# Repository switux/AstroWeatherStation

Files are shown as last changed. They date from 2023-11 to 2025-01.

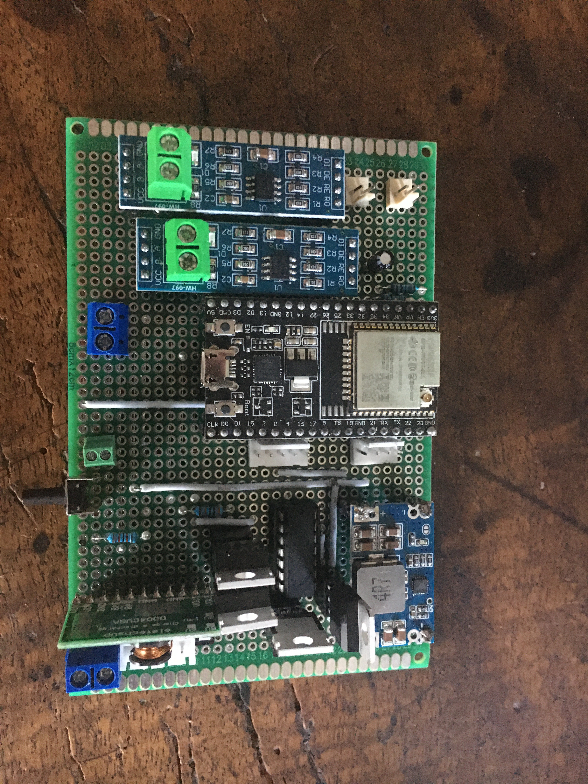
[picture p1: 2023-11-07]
schematics/perfboard_with_components.jpg

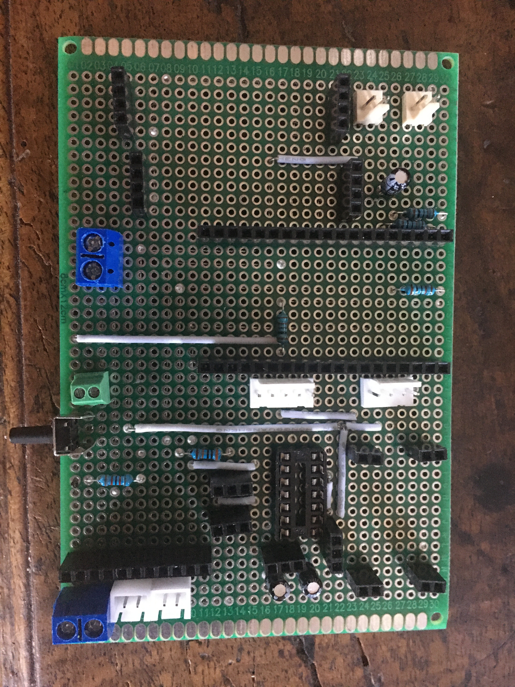
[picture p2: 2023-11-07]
schematics/perfboard_top_view.jpg

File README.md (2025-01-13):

# AstroWeatherStation

ESP32 based weather station with features to help operate an astronomical observatory.



## GOAL

This project aims to provide all the instructions that are needed to build a weather station for remote astronomical observatories.
On top of the usual environmental readings, rain events, cloud coverage and sky quality are reported to allow the safe operation of the observatory.

## PRE-REQUISITES (WIP)

## BUILD INSTRUCTIONS

  - Arduino IDE ( add the lines in bold to ~/.arduino15/packages/esp**xxxx**/hardware/esp**xxxx**/**{version}**/platform.local.txt )

    - The ALPACA web server uses regular expressions that need to be enabled, 

    **compiler.cpp.extra_flags=-DASYNCWEBSERVER_REGEX=1**

    - A sequential build number is embedded in the code every time a build is made (whether it is successful or not)

    **recipe.hooks.prebuild.0.pattern={build.source.path}/../build_seq.sh {build.source.path}**

    For the hook to work, you will also need to create a link (or copy the file) to the file "build.sh" from sketch directory to the path of the sketch book. Sorry for the mess ... if you have a better solution, you are most welcome!

## STATUS & DEVELOPMENT

This is version 3.0 of the project. The current version is 3.0.0 and has hit production.

New features in this version:

  - Hardware
    - Addition of POE module
    - Addition of optional GPS support
    - Addition of an optional I2C UART/GPIO extender (SC16IS750)
    - Two relays to control the observatory dome
    - Input to receive dome status
      
  - Software
    - ASCOM ALPACA Server
    - Support of ultrasonic wind sensors for adverse conditions (frost)
    - Dome closure upon rain event

Improvements:

  - Configuration UI
  - Removed configuration button and replaced by guard time on the reboot button (10s)
  - Clear/cloudy/overcast sky states instead of overcast/clear

The things that might be improved in v3.1 are:

  - Software
    - TBD
  - Hardware
    - TBD

## FEATURES

  - Weather parameters:
  
    - Temperature
    - Pressure
    - Relative humidity
    - Wind speed
    - Wind direction
    - Rain detection
    - Rain intensity
  
  - Astronomical parameters:
  
    - Cloud coverage
    - Solar irradiance
    - Sky Quality Meter
  
  - Alarms for:
  
    - Sensor unavailability
    - Rain event
    - Low battery
    - Rain sensor HW problem
  
  - Operations:

    - External reboot button
    - Debug button (to be pushed when rebooting to activate debug mode)
    - External micro USB socket for debugging (serial console) and firmware updates
    - Configuration mode and runtime configuration updates activable via button

## SPECIFICATIONS

This section is being reworked as there are different hardware setups.

  - Power consumption:
    - Solar panel version:
       - 12mA in sleep mode
       - ~40mA while active (for ~30s)
  - Autonomy: N/A (collecting data)
  - Measures (from sensor specs)
    - Illuminance range: 0-88k Lux ( up to ~730 W/m² )
    - Temperature range: -40°C to +85°C
    - Pressure: 300 to 1100 hPa
    - Wind speed: 0 to 60 m/s

## About the SQM feature

This is now validated.

    - 20°FoV lens put in front of the TSL2591 (comparable to the SQM-Lx)
    - Calibration against my SQM-LE done
    
## Open points

   - The RG9 sensor raises false positives during day because (I guess) of condensation. I try to mitigate this but since it is happening during daytime, it is only a minor issue.

## Runtime configuration interface

## Alarms format

The station sends alarm to an HTTPS endpoint as a JSON string:

{
  "subject": "reason for the alarm",
  "message": "what happened"
}

## Data format

The station sends the data to a web server as a JSON string:

{
  "battery_level":92,
  "timestamp":1675767261,
  "rain_event":0,
  "temp":16.84000015,
  "pres":941.1413574,
  "rh":27.296875,
  "lux":68181,
  "ambient":21.42998695,
  "sky":-3.19000864,
  "direction":45,
  "speed":0,
  "rain":0,
  "sensors":63
}

Where

- battery_level: in % of 4.2V
- timestamp: Unix epoch time
- rain_event: 1 if awakened by the sensor
- temp: in °C
- pres: in hPa (QFE)
- rh: relative humidity in %
- lux: solar illuminance
- ambient: IR sensor ambient temperature
- sky: IR sensor sky temperature (substract ambient to get sky temperature, if below -20° --> sky is clear)
- direction: wind direction 0=N, 45=NE, 90=E, 135=SE, 180=W, 225=SW, 270=W, 315 NW
- speed: in m/s
- rain: 0=None, 1=Rain drops, 2=Very light, 3=Medium light, 4=Medium, 5=Medium heavy, 6=Heavy, 7=Violent
- sensors: available sensors (see source code)

## Tips

- I use female pin headers for the MCU and other boards. I fried a couple of mosfet's during prototyping (even though I have a 15W iron and I am pretty careful) and lost quite some time to troubleshoot the battery level part so I decided to use pin headers too :-)
- I cut the external antenna cable (1m is waaay too long but I could not find a shorter one) and crimped a male SMA to go with the RP-SMA pigtail

## REFERENCES

I found inspiration in the following pages / posts:

  - No need to push the BOOT button on the ESP32 to upload new sketch
    - https://randomnerdtutorials.com/solved-failed-to-connect-to-esp32-timed-out-waiting-for-packet-header
  - Reading battery load level without draining it
    - https://jeelabs.org/2013/05/18/zero-power-measurement-part-2/index.html
  - To workaround the 3.3V limitation to trigger the P-FET of the above ( I used an IRF930 to drive the IRF9540 )
    - https://electronics.stackexchange.com/a/562942
  - Solar panel tilt
    - https://globalsolaratlas.info/
  - TSL2591 response to temperature by Marco Gulino
    - https://github.com/gshau/SQM_TSL2591/commit/9a9ae893cad6f4f078f75384403336409ca85380  
  - Conversion of lux to W/m<sup>2</sup>
    - P. Michael, D. Johnston, W. Moreno, 2020. https://pdfs.semanticscholar.org/5d6d/ad2e803382910c8a8b0f2dd0d71e4290051a.pdf, section 5. Conclusions. The bottomline is 120 lx = 1 W/m<sup>2</sup> is the engineering rule of thumb.

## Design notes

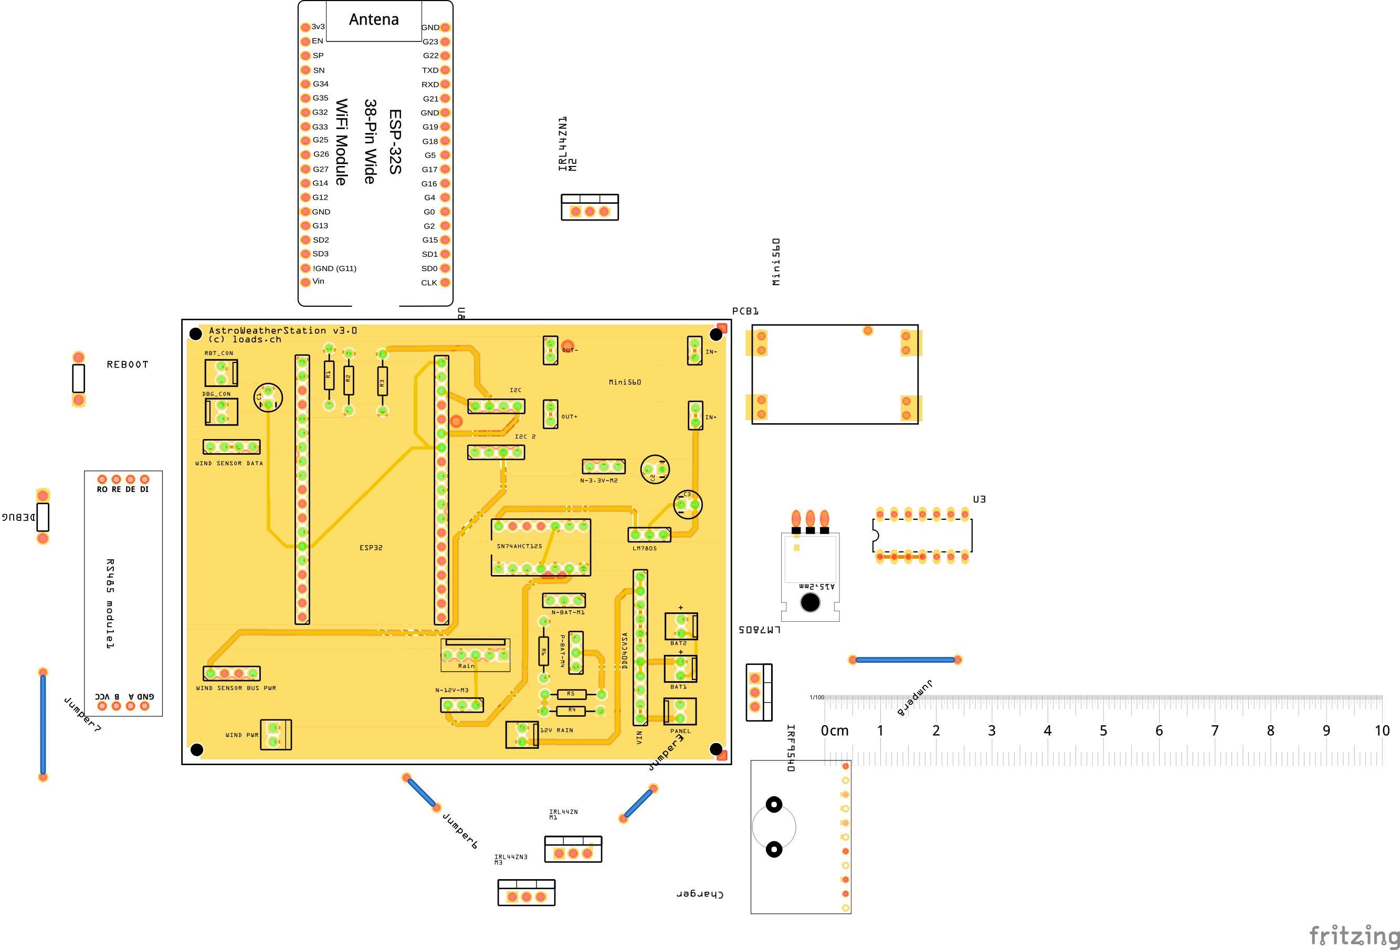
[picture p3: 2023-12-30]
schematics/8x12_AWS_3.0.0_PANEL_pcb.png

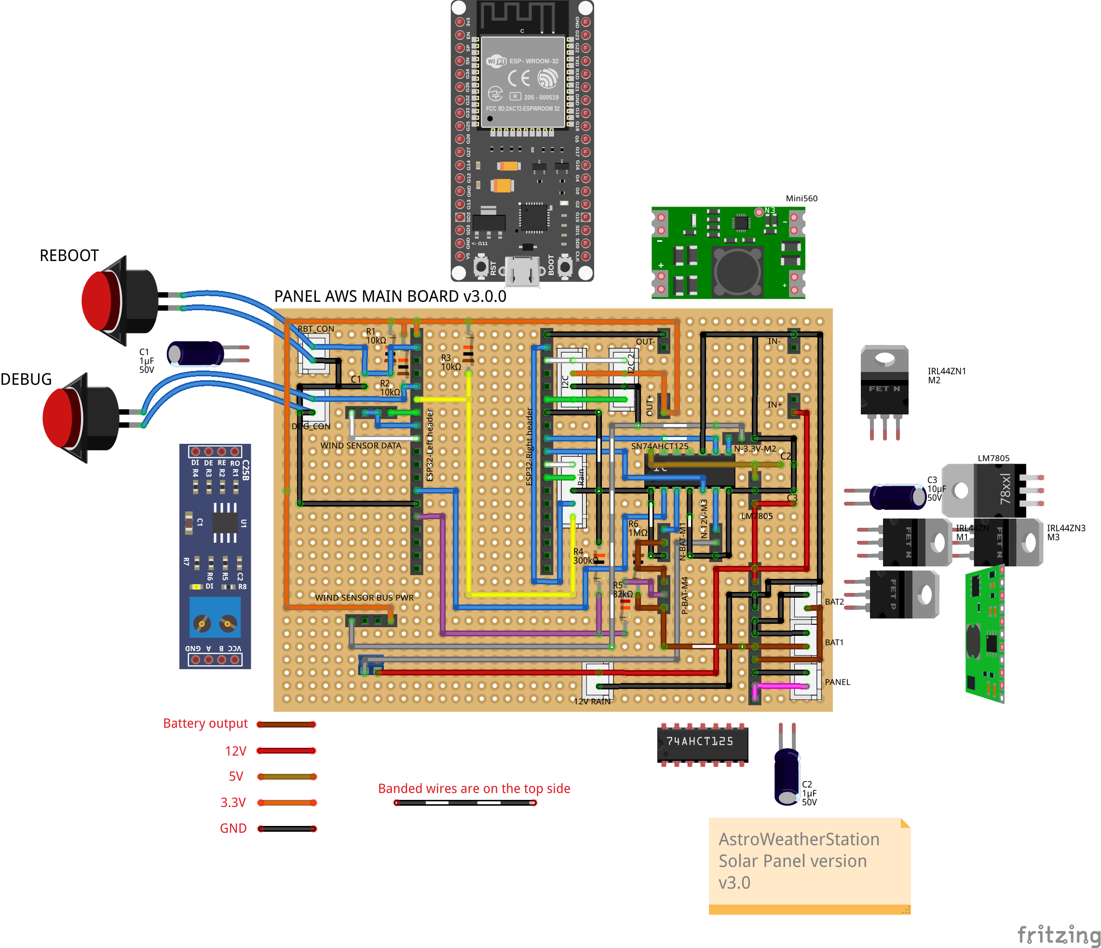
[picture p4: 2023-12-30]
schematics/8x12_AWS_3.0.0_PANEL_bb.png

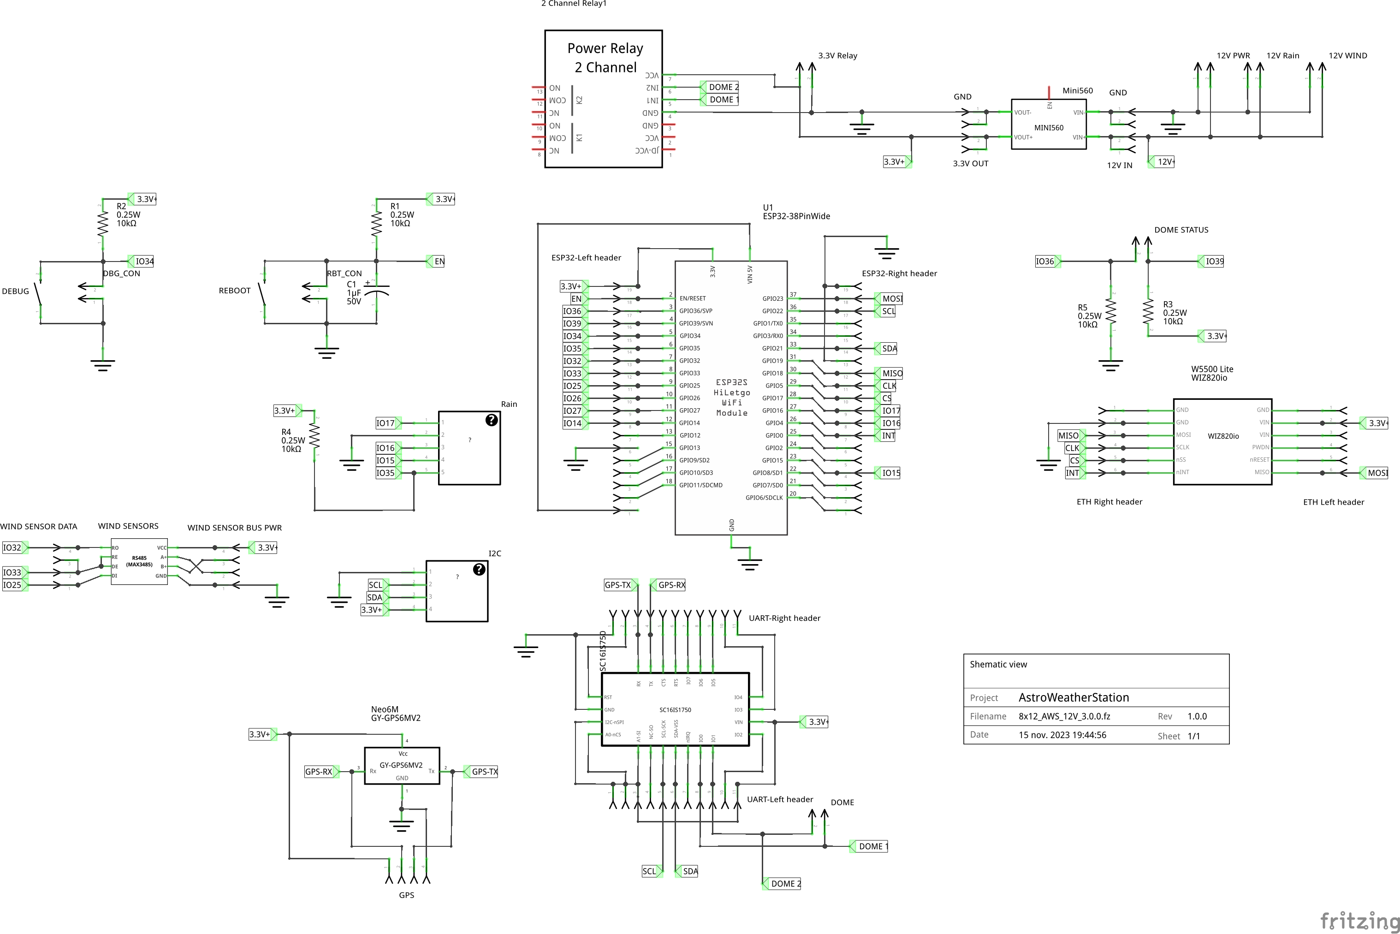
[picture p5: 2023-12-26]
schematics/AWS_12V_3.0.0_schem.png

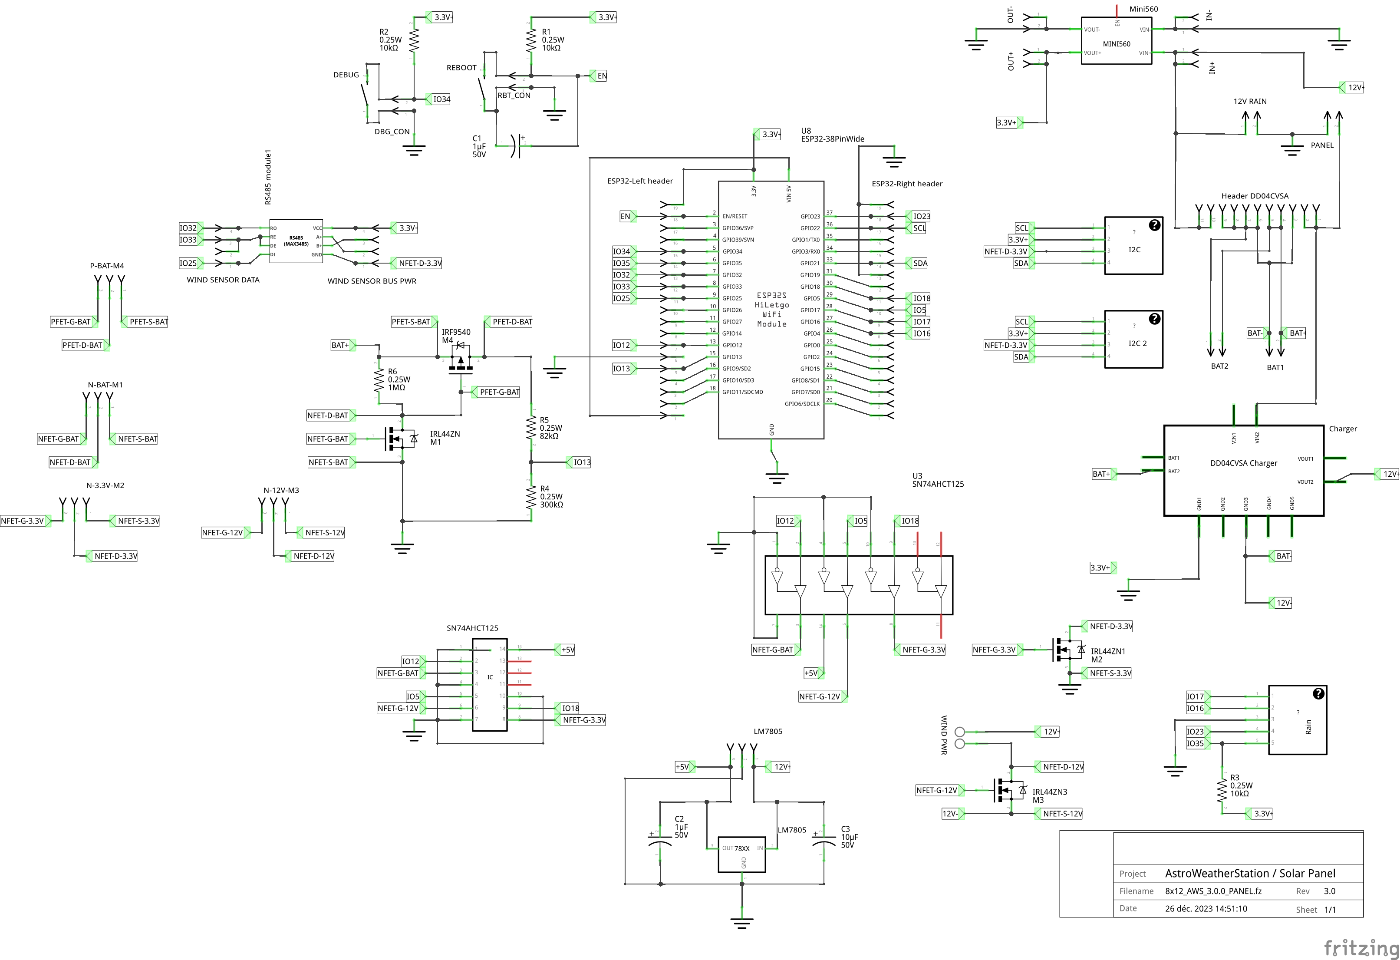
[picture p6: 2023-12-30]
schematics/8x12_AWS_3.0.0_PANEL_schem.png

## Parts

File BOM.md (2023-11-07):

# Bill of materials (WIP)

## Enclosures

- Station: 1x IP67 150x210x47
- Environmental sensor: 1x MISOL Shield (B016Q7LHP2)
- Other sensors: 1x IP67 65x58x35
- Solar panel: 1x 3mm PVC sheet (50x25) (not for POE and 12V versions)

## Boards

- 1x ESP32 WROOM 32U (DevKit C), 38 pins
- 2x MAX485
- 1x SC16IS750 UART/GPIO module
- 1x W5500 mini (for POE version, optional for 12V version)

## Wifi (optional for POE and 12V versions)

- 1x 5dBi external antenna
- 1x SMA male connector 
- 1x IPEX to RP-SMA pigtail

## Ethernet (POE version, and 12V optional)

- 1x W5500 Mini module

## PCB

- 1x 8x12cm universal PCB double side

## Connectors (12V & POE versions)

- 8x KF2510 2pins			(2x buttons, 1x relay pwr, 1x dome status, 1x dome control, 1x 12V wind sensor, 1x 12V RG-9, 1x 12V pwr)
- 1x KF2510 4pins			(I2C)
- 1x KF2510 5pins			(RG9)
- 2x Single row female header 19pins	(ESP32)
- 2x Single row female header 11pins	(SC16IS750)
- 2x Single row female header 5pins	(W5500)
- 5x Single row female header 4pins	(GPS,MAX485)
- 4x Single row female header 2pins	(Mini560)

## Cables

- 1x IP67 micro USB cable male to female, 30cm
- 1.5m 22AWG UL2464 4 cores
- 1.5m 24AWG single core
- 1m 22AWG UL2464 7 cores
- 0.5m 20AWG UL2464 2 cores
- 0.5m 22AWG

## Sensors

- 1x TLS2591
- 1x MLX90614 BAA
- 1x BME280
- 1x RS485 Wind vane
- 1x RS485 Anemometer
- 1x Hydreon RG-9
- 1x Neo-8M/Neo-6M GPS

## Power

- 1x Mini560 step down 3.3V
- 1x DD04CVSA 12V (not for POE and 12V versions)
- 2x LiPo battery 103450 (not for POE and 12V versions)
- 1x Solar panel 6V 3W (not for POE and 12V versions)
- 1x 48V POE PD (for IPTV camera) 12V2A (only for POE version)

## Small parts -- electronics

- 4x 0.25W 10k resistor
- 1x 0.25W 82k resistor (only for solar panel version)
- 1x 0.25W 300k resistor (only for solar panel version)
- 3x 0.25W 1M resistor (only for solar panel version)

- 1x 10uF electrolytic capacitor
- 3x IRZN44L (only for solar panel version)
- 1x LM 7805 (only for solar panel version)
- 1x SN74AHCT125 (only for solar panel version)

## Small parts -- mechanics

- 8x PG7 cable gland
- 8x M2.6 8mm screws
- 1x IP55 Push button red (reboot)
- 1x IP55 Push button black (debug/config)
- 1deg FoV LED clear lens with holder (diam. 13mm)

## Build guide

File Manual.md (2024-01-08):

# !! WIP DOCUMENT !!

# HW Variants

There are at least two PCB variants:
- Solar Panel
- 12V / PoE

The solar panel comes with a charger and a set of MOSFETs to switch on/off sensors and battery charge level reading.

The 12V/PoE does not include a charger, batteries, MOSFETs, etc. 

This is why there are two versions in the schematics folder. Here are the possible HW variants and features:

| | Ethernet | GPIO extender | GPS |
|-|---|---|-----|
|Solar panel | No | No | No |
| 12V/PoE | Optional | Optional | Optional |

# HW Configuration companion app

Since a unique firmware version is shared between variants, it is necessary to store the HW features in a way that cannot be accidentally changed or altered during runtime config. Since ESP32 does not have any EPROM, a NVS solution is taken but which must not be modified by the firmware itself. This is the reason why a small configuration app has been written to allow the setting of the HW features.

_Insert GH link to the app_

The app will allow you, from --for example-- the Arduino IDE serial monitor, to enter your choices and then to restart the MCU so that you can check that the values have been correctly saved.

**You must first upload this app on the MCU before anything else.**

# Configuration

In case you plan to test the same basic config on different MCU's you can amend your default configuration by changing data/aws.conf.dfl which contains the following JSON string:

{"pref_iface":2,"alpaca_iface":2,"config_iface":2}

Then, from the arduino IDE, you can upload this file and get an immediately usable station from a "blank" MCU provided an AWS firmware has been uploaded. This is also handy when you badly screw up your config. This will remove the aws.conf file and leave you with a sane was.conf.dfl file :-)

# Configuration reference
## Power supply mode
- 0: Solar panel
- 1: 12V DC
- 2: PoE
## PCB version
 - "1.x"
 - "2.x"
 - "3.x"

## Interface numbering
- 0 : WIFI AP
- 1: WIFI STA
- 2: Ethernet

## IP Mode
- 0: DHCP
- 1: Manual

## Configuration items
- **eth_ip_mode**: 0, 1
  - Ethernet IP configuration
- **eth_ip**: xxx.xxx.xxx.xxx/CIDR mask
  - Ethernet IP address, overriden of **eth_ip_mode** is DHCP. CIDR mask value. e.g.: 24 for a 255.255.255.0 (see [Wikipedia article](https://en.wikipedia.org/wiki/Classless_Inter-Domain_Routing#IPv4_CIDR_blocks "Wikipedia article") for more information)
- **pcb_version**:
  - Indicates the hardware/PCB design if the station, you should not change the default value unless you understand the implications
- **pwr_mode**: 
  - Sets the type of power supply, when set to "Solar panel", the station will sleep most of the time and wake up at fixed intervals to update sensor values and send them to a server (see **url_path**  and  **remote_server** parameters )
- **has_ethernet**: 1 or 0
  - Activates ethernet support, only supported with pcb_version >= 3.x
- **has_sc16is750**: 1 or 0
  - Activates SC16IS750 UART/GPIO extender, only supported with pcb_version >= 3.x
- **pref_iface**: 0, 1, 2
  - Preferred interface to connect to the station.
- **alpaca_iface**: 0, 1, 2
  - Default interface of the ALPACA server.
- **config_iface**: 0,1,2
  - Default interface of the configuration server.

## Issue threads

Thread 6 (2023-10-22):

Fix power consumption instability

switux, 2023-10-22:

switux, 2023-12-07:
The solar panel version has erratic battery load profiles, we need to understand if it is a perfboard issue, a defective part or something more fundamental.

switux, 2023-12-17:
Most probably found the issue: badly placed battery charge reading mosfet, also resulting in erratic readings. Reworked the schema while removing a MAX485.

switux, 2023-12-30:
Moving the n-fet as high side switch was a bad idea, now replaced by PFET/NFET combination and it works. Maybe a side effect but the power consumption rate is back to normal.

Closed 2023-12-30.

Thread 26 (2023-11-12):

Need to know if the dome is closing or opening

switux, 2023-11-12:
ASCOM dome device has a shutterstatus which can be:
	Open,
	Closed,
	Opening,
	Closing,
	Error

Open/Close can be determined from the dome GPIO pin.

Since we are not the only ones controlling the dome, we can only rely on our closeshutter/openshutter actions. Is that correct?

switux, 2024-05-22:
There are now two GPIOs:

- One that is HIGH if the shutter is CLOSED
- One that is HIGH if the shutter is OPEN

If one of these goes LOW, it's reasonable to say that the shutter is either opening or closing

Closed 2024-05-22.

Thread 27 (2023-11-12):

Can we open the dome?

switux, 2023-11-12:
ASCOM dome device has the openshutter action, what do we do since we can only close the dome?

For the moment, we will return an error code 1036 (action not implemented)

switux, 2023-12-07:
Need to check with one customer if we can open the dome or if we are limited to closing it

switux, 2024-01-12:
After discussion, yes.

Closed 2024-01-12.

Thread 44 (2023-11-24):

Should at last inform that if MLX is down, SQM reading will be slightly less accurate

switux, 2023-11-24:

switux, 2024-03-05:
The temperature of the TSL sensor is the same as that of the MLX sensor and the TSL response varies with the temperature

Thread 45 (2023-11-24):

HTTP_PUT is overriden by wrong value in alpaca.cpp

switux, 2023-11-24:

switux, 2023-12-07:
One of the libraries somehow redefines (or sets) HTTP_PUT to a value different from 8 which is the one expected by the async web server

switux, 2024-01-03:
In my case the mismatch is introduced in:

~/.arduino15/packages/esp32/hardware/esp32/2.0.14/tools/sdk/esp32/include/nghttp/port/include/http_parser.h

which sets HTTP_PUT to 4 instead of 8 in ESPAsyncWebSrv.h

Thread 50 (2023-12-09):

Crash in solar panel model mode after probing rain sensor

switux, 2023-12-09:

Closed 2023-12-26.

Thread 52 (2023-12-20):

[ALPACA] ObservingConditions / Unimplemented Endpoint

ispybadguys, 2023-12-20:
Great project!

I am not sure what I am going wrong but when I try and connect using Ascom Diagnostics to with the dome or the observing conditions monitor I am getting:

[DEBUG] ALPACA: unimplemented endpoint: 8 /api/v1/observingconditions/0/connected, with parameters: (ClientTransactionID=1) (ClientID=49360) (Connected=True)

Any help is appreciated.

Kurt

switux, 2023-12-20:
Hello

Happy to see you like it! I need more details, can you please dump the contents of the boot time banner?

Thanks
F

ispybadguys, 2023-12-20:
I did change the datamancers.net website to a dummy because I didn't know exactly if this would cause problems. I also there are a few things that I didn't understand in the configuration but ASCOM DIagonistics does discover the device and tries to connect. At this point I do not actually have any external hardware attached.

22:50:40.259 -> ##############################################################################################
22:50:40.259 -> # AstroWeatherStation                                                                        #
22:50:40.259 -> #  (c) Lesage Franck - lesage@datamancers.net                                                #
22:50:40.259 -> #--------------------------------------------------------------------------------------------#
22:50:40.259 -> # MCU              : Model ESP32-PICO-D4 Revision 1                                          #
22:50:40.259 -> # WIFI Mac         : 64:b7:08:80:fb:b8                                                       #
22:50:40.259 -> # Power Mode       : 12V DC                                                                  #
22:50:40.259 -> # PCB version      : 3.x                                                                     #
22:50:40.259 -> # Anemometer model : PR-3000-FSJT-N01                                                        #
22:50:40.259 -> # Windvane model   : PR-3000-FXJT-N01                                                        #
22:50:40.259 -> # Ethernet present : Yes                                                                     #
22:50:40.259 -> # Firmware         : 3.0.0.0-20231124                                                        #
22:50:40.259 -> #--------------------------------------------------------------------------------------------#
22:50:40.259 -> # GPIO PIN CONFIGURATION                                                                     #
22:50:40.259 -> #--------------------------------------------------------------------------------------------#
22:50:40.259 -> # Anemometer : RX=33 TX=25 CTRL=32                                                           #
22:50:40.259 -> # Wind vane  : RX=26 TX=14 CTRL=27                                                           #
22:50:40.259 -> # RG9        : RX=17 TX=16 MCLR=15 RAIN=35                                                   #
22:50:40.350 -> # DEBUG      : 34                                                                            #
22:50:40.350 -> #--------------------------------------------------------------------------------------------#
22:50:40.350 -> # RUNTIME CONFIGURATION                                                                      #
22:50:40.350 -> #--------------------------------------------------------------------------------------------#
22:50:40.350 -> # AP SSID      : AstroWeatherStation                                                         #
22:50:40.350 -> # AP PASSWORD  : xxxxxxxxxx                                                               #
22:50:40.350 -> # AP IP        : 192.168.1.1/24                                                              #
22:50:40.350 -> # AP Gateway   : 192.168.1.1                                                                 #
22:50:40.350 -> # STA SSID     : Kurt's Wi-Fi Network                                                        #
22:50:40.350 -> # STA PASSWORD : xxxxxxxxx                                                               #
22:50:40.350 -> # STA IP       : 192.168.1.62/24                                                             #
22:50:40.430 -> # STA Gateway  : 192.168.1.1                                                                 #
22:50:40.430 -> # SERVER       : www.tempestwx.com                                                           #
22:50:40.430 -> # URL PATH     : /station/27577/                                                             #
22:50:40.430 -> # TZNAME       : MST7MDT                                                                     #
22:50:40.430 -> # ROOT CA      : -----BEGIN CERTIFICATE----- MIIFazCCA1OgAwIBAgIRAIIQz7DSQONZRGPgu2OCiwAwDQY #
22:50:40.430 -> # JKoZIhvcNAQELBQAw TzELMAkGA1UEBhMCVVMxKTAnBgNVBAoTIEludGVybmV0IFNlY3VyaXR5IFJlc2Vh cmNoIEd #
22:50:40.430 -> # yb3VwMRUwEwYDVQQDEwxJU1JHIFJvb3QgWDEwHhcNMTUwNjA0MTEwNDM4 WhcNMzUwNjA0MTEwNDM4WjBPMQswCQYD #
22:50:40.430 -> # VQQGEwJVUzEpMCcGA1UEChMgSW50ZXJu ZXQgU2VjdXJpdHkgUmVzZWFyY2ggR3JvdXAxFTATBgNVBAMTDElTUkcgU #
22:50:40.430 -> # m9vdCBY MTCCAiIwDQYJKoZIhvcNAQEBBQADggIPADCCAgoCggIBAK3oJHP0FDfzm54rVygc h77ct984kIxuPOZXo #
22:50:40.430 -> # Hj3dcKi/vVqbvYATyjb3miGbESTtrFj/RQSa78f0uoxmyF+ 0TM8ukj13Xnfs7j/EvEhmkvBioZxaUpmZmyPfjxwv6 #
22:50:40.430 -> # 0pIgbz5MDmgK7iS4+3mX6U A5/TR5d8mUgjU+g4rk8Kb4Mu0UlXjIB0ttov0DiNewNwIRt18jA8+o+u3dpjq+sW T8 #
22:50:40.430 -> # KOEUt+zwvo/7V3LvSye0rgTBIlDHCNAymg4VMk7BPZ7hm/ELNKjD+Jo2FR3qyH B5T0Y3HsLuJvW5iB4YlcNHlsdu8 #
22:50:40.732 -> # 7kGJ55tukmi8mxdAQ4Q7e2RCOFvu396j3x+UC B5iPNgiV5+I3lg02dZ77DnKxHZu8A/lJBdiB3QW0KtZB6awBdpUK #
22:50:40.732 -> # D9jf1b0SHzUv KBds0pjBqAlkd25HN7rOrFleaJ1/ctaJxQZBKT5ZPt0m9STJEadao0xAH0ahmbWn OlFuhjuefXKn #
22:50:40.732 -> # EgV4We0+UXgVCwOPjdAvBbI+e0ocS3MFEvzG6uBQE3xDk3SzynTn jh8BCNAw1FtxNrQHusEwMFxIt4I7mKZ9YIqio #
22:50:40.732 -> # ymCzLq9gwQbooMDQaHWBfEbwrbw qHyGO0aoSCqI3Haadr8faqU9GY/rOPNk3sgrDQoo//fb4hVC1CLQJ13hef4Y53 #
22:50:40.732 -> # CI rU7m2Ys6xt0nUW7/vGT1M0NPAgMBAAGjQjBAMA4GA1UdDwEB/wQEAwIBBjAPBgNV HRMBAf8EBTADAQH/MB0GA1 #
22:50:40.732 -> # UdDgQWBBR5tFnme7bl5AFzgAiIyBpY9umbbjANBgkq hkiG9w0BAQsFAAOCAgEAVR9YqbyyqFDQDLHYGmkgJykIrGF #
22:50:40.732 -> # 1XIpu+ILlaS/V9lZL ubhzEFnTIZd+50xx+7LSYK05qAvqFyFWhfFQDlnrzuBZ6brJFe+GnY+EgPbk6ZGQ 3BebYht #
22:50:40.732 -> # F8GaV0nxvwuo77x/Py9auJ/GpsMiu/X1+mvoiBOv/2X/qkSsisRcOj/KK NFtY2PwByVS5uCbMiogziUwthDyC3+6W #
22:50:40.732 -> # VwW6LLv3xLfHTjuCvjHIInNzktHCgKQ5 ORAzI4JMPJ+GslWYHb4phowim57iaztXOoJwTdwJx4nLCgdNbOhdjsnvz #
22:50:40.732 -> # qvHu7Ur TkXWStAmzOVyyghqpZXjFaH3pO3JLF+l+/+sKAIuvtd7u+Nxe5AW0wdeRlN8NwdC jNPElpzVmbUq4JUag #
22:50:40.732 -> # EiuTDkHzsxHpFKVK7q4+63SM1N95R1NbdWhscdCb+ZAJzVc oyi3B43njTOQ5yOf+1CceWxG1bQVs5ZufpsMljq4Ui #
22:50:40.732 -> # 0/1lvh+wjChP4kqKOJ2qxq 4RgqsahDYVvTH9w7jXbyLeiNdd8XM2w9U/t7y0Ff/9yi0GE44Za4rF2LN9d11TPA mR #
22:50:40.732 -> # GunUHBcnWEvgJBQl9nJEiU0Zsnvgc/ubhPgXRR4Xq37Z0j4r7g1SgEEzwxA57d emyPxgcYxn/eR44/KJ4EBs+lVDR #
22:50:40.732 -> # 3veyJm+kXQ99b21/+jh5Xos1AnX5iItreGCc= -----END CERTIFICATE-----                            #
22:50:40.732 -> # DOME         : Yes                                                                         #
22:50:40.732 -> # SQM/SOL.IRR. : No                                                                          #
22:50:40.732 -> # CLOUD SENSOR : No                                                                          #
22:50:40.732 -> # RH/TEMP/PRES : No                                                                          #
22:50:40.732 -> # WINDVANE     : No                                                                          #
22:50:40.732 -> # ANEMOMETER   : Yes                                                                         #
22:50:40.732 -> # RAIN SENSOR  : No                                                                          #
22:50:40.758 -> ##############################################################################################

switux, 2023-12-20:
That's weird, I cannot reproduce your issue and it just does not make sense ... may I ask that you try the version found in https://www.datamancers.net/images/AstroWeatherStation_3.0.0.tgz that contains a couple of additional traces and send me the complete debug log?

Also, what tool do you use to test the alpaca api (version, etc.) ? On my side, I use ConformU Version 2.0.0 (Build 16486))

You may have to change a couple of settings in aws.conf as this version contains other changes that are not committed yet on GH, like I said, it's still WIP :-)

Thanks

ispybadguys, 2023-12-20:
Thanks
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
ispybadguys, 2023-12-26:
Please excuse the reply to my reply I tried the following. I added a route

 server->on( "/api/v1/observingconditions/0/connected", 8, std::bind( &alpaca_server::dispatch_request, this, std::placeholders::_1 ));

and this route actually seems to catch the connected url.

I get this response in the Serial monitor

21:21:44.354 -> [DEBUG] NTP Synchronised. Time and date: 2023-12-25 21:21:44
21:21:48.628 ->
21:21:48.628 -> [DEBUG] Alpaca client request parameters: (Connected=True)(ClientID=1)(ClientTransactionID=1)
21:21:49.350 -> [DEBUG] NTP Synchronised. Time and date: 2023-12-25 21:21:49

but ASCOM Conform still complains

21:21:47.517 ASCOM Universal Device Conformance Checker Version 2.0.0.16486, Build time: Mon 29 May 2023 08:03:52
21:21:47.518
21:21:47.518 Operating system is Microsoft Windows 10.0.22631 64bit, Application is 64bit.
21:21:47.518
21:21:47.519 Alpaca device: AstroWeatherstation (192.168.1.62:8080 ObservingConditions/0)
21:21:47.519
21:21:47.522 CreateDevice                        INFO     Creating Alpaca device: IP address: 192.168.1.62, IP Port: 8080, Alpaca device number: 0
21:21:47.526 CreateDevice                        INFO     Alpaca device created OK
21:21:47.526 CreateDevice                        INFO     Successfully created driver
21:21:48.528 ConformanceCheck                    OK       Driver instance created successfully
21:21:48.528
21:21:48.528 Connect to device
21:21:52.128 Connected                           ISSUE    Exception when setting Connected to True: The response ended prematurely.
21:21:52.130
21:21:52.130 ConformanceCheck                             Further tests abandoned.
21:21:52.130
21:21:52.131 Your device had 1 issue, 0 errors and 0 configuration alerts
21:21:52.131
21:21:52.131 Issue Summary
21:21:52.131 Connected                           ISSUE    Exception when setting Connected to true - testing abandoned: The response ended prematurely.

Kurt

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

switux, 2023-12-26:
Hello and merry christmas too!

The more I think about it, the more an issue with a library becomes a possibility, especially with the RE. Which version of ESPASyncWebSrv do you have?

Can you also list the libraries that got compiled?

BTW I pushed code yesternight on GH , not that it will solve your issue, but contains fixes for various bugs :-)

Cheers,
F

ispybadguys, 2023-12-26:
Franck

I have 1.2.7 installed author is dvarrel

I found where it is going by modifying this code:

void alpaca_server::dispatch_request( AsyncWebServerRequest *request )
{Serial.printf("alpaca_server::dispatch_request\n" );
	if ( !extract_transaction_details( request, ( request->method() != HTTP_GET ) )) {
    Serial.printf("alpaca_server::dispatch_request != HTTP_GET\n" );
		request->send( 400, "text/plain", transaction_details );
		return;
	}
  Serial.printf("alpaca_server::dispatch_request request->pathArg(0).c_str()=%s\n",request->pathArg(0).c_str() ); // KRL
	switch( str2int( request->pathArg(0).c_str() )) {

		case str2int( "dome" ):
			dispatch_dome_request( request );
			break;

		case str2int( "observingconditions" ):
      Serial.printf("DISPATCH OC\n" ); //KRL
			dispatch_observingconditions_request( request );
			break;

		case str2int(
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

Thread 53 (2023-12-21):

[SENSOR MNGR] Crash when no I2C sensor is configured.

switux, 2023-12-21:
Derived from #52

21:38:04.380 -> [INFO] AstroWeatherStation is booting...
21:38:04.518 -> [DEBUG] Empty config file [/aws.conf]
21:38:04.518 -> [DEBUG] File successfuly read... and configuration format is valid... OK!
21:38:04.518 -> [INFO] Using minimal/factory config file.
21:38:04.518 -> [DEBUG] Booting in STA mode.
21:38:04.609 -> [INFO] Attempting to connect to SSID [Kurt's Wi-Fi Network] ... OK. Using IP [192.168.1.62]
21:38:07.621 -> Guru Meditation Error: Core  1 panic'ed (LoadProhibited). Exception was unhandled.
21:38:07.621 ->
21:38:07.621 -> Core  1 register dump:
21:38:07.621 -> PC      : 0x401981fb  PS      : 0x00060130  A0      : 0x800d7490  A1      : 0x3ffb21a0
21:38:07.621 -> A2      : 0x00000000  A3      : 0x00000000  A4      : 0x3f400cad  A5      : 0x3ffb81e8
21:38:07.621 -> A6      : 0x3ffb99dc  A7      : 0x3f4008c9  A8      : 0x800d52c0  A9      : 0x3ffb2180
21:38:07.621 -> A10     : 0x00000001  A11     : 0x00000001  A12     : 0x00000017  A13     : 0x3ffb1e00
21:38:07.667 -> A14     : 0x00000009  A15     : 0x3ffb2000  SAR     : 0x00000004  EXCCAUSE: 0x0000001c
21:38:07.667 -> EXCVADDR: 0x000000b8  LBEG    : 0x4008cc71  LEND    : 0x4008cc81  LCOUNT  : 0xfffffffc
21:38:07.667 ->
21:38:07.667 ->
21:38:07.667 -> Backtrace: 0x401981f8:0x3ffb21a0 0x400d748d:0x3ffb21c0 0x400dc0cf:0x3ffb2260 0x400f85ba:0x3ffb2290

PC: 0x401981fb
EXCVADDR: 0x000000b8

Decoding stack results
0x401981f8: AWSSensorManager::get_i2c_mutex() at Z:\Arduino 2022\AstroWeatherStation_3.0.0/AWSSensorManager.cpp line 69
0x400d748d: AstroWeatherStation::initialise() at Z:\Arduino 2022\AstroWeatherStation_3.0.0/AWS.cpp line 451
0x400dc0cf: setup() at Z:\Arduino 2022\AstroWeatherStation_3.0.0/AstroWeatherStation_3.0.0.ino line 46
0x400f85ba: loopTask(void*) at C:\Users\Kurt\AppData\Local\Arduino15\packages\m5stack\hardware\esp32\2.0.8\cores\esp32\main.cpp line 42

The code that is crashing is:

68: SemaphoreHandle_t AWSSensorManager::get_i2c_mutex( void )
69: {
70:	return i2c_mutex;
71: }

Closed 2023-12-26.

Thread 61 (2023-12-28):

Wind gust must not be -1 even if no wind sensor is found or attached

switux, 2023-12-28:
This causes an issue in ALPACA conformance tests.

Closed 2023-12-28.

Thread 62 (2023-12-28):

[PANEL] N-FET as high side switch for battery level readings is a no go

switux, 2023-12-28:
Redesigned 1.x and 2.x to get rid of the P-FET/N-FET combination but I have been too greedy and forgot that N-FET as a high side switch is not straightforward. It would need about 10V (max battery level 4.2V + 5V margin) on the gate pin and I have no way of getting this without unnecessary hassle.

I thus rollbacked to this combination only for the battery switch and kept low side N-FET for 3.3V & 12V power switches.

switux, 2023-12-30:
No more reading issues.

Closed 2023-12-30.

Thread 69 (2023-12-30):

[ALPACA] ObservingConditions eturns "Done not connected" rather than "Sensor not connected"

switux, 2023-12-30:
When (for instance) BME is not available, the server will return misleading error message

Closed 2023-12-30.

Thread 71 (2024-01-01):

Skipped configuration rollback sometimes causes a crash because sensors are not initialised

switux, 2024-01-01:

Closed 2024-01-01.

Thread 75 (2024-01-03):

NPE crash when alpaca refresh request of wind gust and there the wind sensor is not initialised

switux, 2024-01-03:

Closed 2024-01-03.

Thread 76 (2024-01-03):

[ALPACA] When sensors are not initialised, do not return any value but say the sensor is not connected

switux, 2024-01-03:

switux, 2024-01-03:
Now returning a 1024 error

Closed 2024-01-03.

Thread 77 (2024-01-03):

[ALPACA] rainrate must not return "NotConnected" error when the sensor is not initialised

switux, 2024-01-03:

switux, 2024-01-03:
Now returning 1024

Closed 2024-01-03.

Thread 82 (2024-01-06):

Crash in case of massive alpaca request sequence during sensor initialisation

switux, 2024-01-06:
There is no easy fix for this. The solution will be to move alpaca server startup after sensor initialisation is complete.

Closed 2024-01-06.

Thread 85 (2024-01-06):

[ALPACA] ObservingConditions / TimeSinceLastUpdate error since fix of #76

switux, 2024-01-06:

switux, 2024-01-06:
No value was returned because of bogus check of sensor connection state

Closed 2024-01-06.

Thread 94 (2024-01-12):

[SQM] Temperature correction factor is wrong for negative values

switux, 2024-01-12:
1. The graph from which the formula has been created does not go below 0°
2. The formula's validity domain is R+* :-)

Closed 2024-01-12.

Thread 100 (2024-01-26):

Remove code defects / Part 1 of x

switux, 2024-01-26:
A first batch of sonarcloud issues, easiest ones

Closed 2024-01-26.

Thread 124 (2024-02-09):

How to handle dome control and station reboot?

switux, 2024-02-09:
Since dome control is done via pulled-down pins, it is possible that the pins get grounded during a reboot. How do we manage this?

switux, 2024-02-18:
Fixed. GPIO's are up by default until we set them in OUTPUT mode, in that case we must write HIGH immediately after.

Closed 2024-02-23.

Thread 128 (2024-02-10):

Unsafe Conditions

bucks0042, 2024-02-10:
Please consider to implement following unsafe condition :

Unsafe if :

- Cloudly for more as x seconds (To be defined in user interface)
- Overcast -> Immediately
- Rain -> Immediately
- wind : more than x seconds (TBDF in user interface) if wind is more as x m/s, immediately in case of wind more as y m/s

Revert to safe :

- immediately for cloudy to clear
- after x seconds for overcast
- after x seconds for Rain
- immediately for wind "x" after x seconds for wind "y"

switux, 2024-02-18:
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

switux, 2024-02-19:
It kind of works but there are some corner cases to be sorted out. I suggest we agree on a (simple) state machine asap.

Closed 2024-02-23.

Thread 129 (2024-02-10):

12v controlable relay for roof moving and roof open/closed

bucks0042, 2024-02-10:
implement two 12v relay which send 3.3v to the board when closed in order to send both informations

Closed 2025-01-07.

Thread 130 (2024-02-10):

add limits to graphs

bucks0042, 2024-02-10:
For the display of the graph, please implement a line which is showing the current "unsafe limit"

switux, 2024-02-19:
Add max values to json_sensor_data

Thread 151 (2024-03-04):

Sometimes OTA upgrade fails with a crash during download

switux, 2024-03-04:
It's caused by a WDT timeout on async_tcp. Current workaround is to

1. add wdt timer resets here and there in the ESPOTAPull library and in the AWS callback function.
2. stop tasks in the station's ota check function
3. if the dashboard tab on the browser is active, stop polling

And even then, it's not always enough. In that case, one needs to retry the upgrade ...

switux, 2024-03-05:
Found out that I may have other sessions connecting to the station's webserver which could cause the async_tcp to hang

switux, 2024-03-09:
Not much to be done as it's the async tcp that hangs, just avoid poking the station during and OTA update ...

Closed 2024-03-09.

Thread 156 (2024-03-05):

Compare results between MLX's ambient temp and BLE280 temp to determine corrected sky temperature

switux, 2024-03-05:

Closed 2024-05-22.

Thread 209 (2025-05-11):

Status led pinout has changed between PCB 3.0.1 and 3.0.2

switux, 2025-05-11:
Blue and red leds had to be swapped, code needs to support both versions

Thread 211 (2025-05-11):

In panel version, current draw is too high

switux, 2025-05-11:
CPU has to be throttled and BT shut down

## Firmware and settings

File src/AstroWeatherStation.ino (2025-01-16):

/*	
	AstroWeatherStation.ino

	(c) 2023-2024 F.Lesage

	1.0.x - Initial version.
	1.1.x - Refactored to remove unnecessary global variables
	1.2.x - Added experimental SQM feature
	1.3.x - Added OTA Update / Rudimentary configuration webserver / Persistent configuration
	2.0.x - Added button to enter configuration mode
	3.0.0 - Complete rework to become more modular
	
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
	You should have received a copy of the GNU General Public License along
	with this program. If not, see <https://www.gnu.org/licenses/>.
*/
#include <esp_task_wdt.h>
// Keep these two to get rid of compile time errors because of incompatibilities between libraries
#include <AsyncUDP_ESP32_W5500.hpp>
#include <ESPAsyncWebServer.h>
#include "soc/rtc_wdt.h"

#include "gpio_config.h"
#include "common.h"
#include "AstroWeatherStation.h"

extern char			catch_rain_event;

const etl::string<12>		REV					= "3.0.0";
const unsigned long			US_SLEEP			= 5 * 60 * 1000000;					// 5 minutes
const unsigned long long	US_HIBERNATE		= 1 * 24 * 60 * 60 * 1000000ULL;	// 1 day

AstroWeatherStation station;

void setup()
{
	Serial.begin( 115200 );
	delay( 500 );

	if ( !station.initialise()) {
		
		Serial.printf( "[CORE      ] [PANIC] ===> AstroWeatherStation did not properly initialise. Stopping here! <===\n" );
		while( true ) {
		}
	}

	if ( station.on_solar_panel() ) {

		if ( !station.is_rain_event() ) {

			station.read_sensors();
			station.send_data();
			if ( station.get_station_data()->health.battery_level > 50 )
				station.check_ota_updates( true );

		} else
		
			station.handle_event( aws_event_t::RAIN );

		esp_sleep_enable_timer_wakeup( US_SLEEP );

		if ( station.has_device( aws_device_t::RAIN_SENSOR ) ) {

			if ( catch_rain_event ) {

				Serial.printf( "[CORE      ] [INFO ] Monitoring rain sensor.\n" );
				esp_sleep_enable_ext0_wakeup( GPIO_RAIN_SENSOR_RAIN, LOW );

			 } else

				Serial.printf( "[CORE      ] [INFO ] Not monitoring rain sensor.\n" );
		}
		Serial.printf( "[CORE      ] [INFO ] Entering sleep mode.\n" );
		esp_deep_sleep_start();
	}
}

void loop()
{
	if ( station.on_solar_panel() ) {

		while (true) {

			Serial.printf( "[CORE      ] [PANIC] Must not execute this code when running on solar panel!\n" );
			delay( 10000 );
		}
	}

	while( true ) {
		delay( 100 );
	}
}

void IRAM_ATTR _handle_dome_shutter_open_change( void )
{
	station.handle_event( aws_event_t::DOME_SHUTTER_OPEN_CHANGE );
}

void IRAM_ATTR _handle_dome_shutter_closed_change( void )
{
	station.handle_event( aws_event_t::DOME_SHUTTER_CLOSED_CHANGE );
}

void IRAM_ATTR _handle_rain_event( void )
{
	station.handle_event( aws_event_t::RAIN );
}

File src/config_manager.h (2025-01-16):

/*
  	config_manager.h

	(c) 2023-2024 F.Lesage

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
	You should have received a copy of the GNU General Public License along
	with this program. If not, see <https://www.gnu.org/licenses/>.
*/

#pragma once
#ifndef _config_manager_H
#define _config_manager_H

#include <ArduinoJson.h>

#include "device.h"
enum struct aws_iface : int {

	wifi_ap,
	wifi_sta,
	eth

};

enum struct aws_wifi_mode : int {

	sta,
	ap,
	both

};

enum struct aws_pwr_src : int {

	panel,
	dc12v,
	poe

};

enum struct aws_ip_mode : int {

	dhcp,
	fixed

};

const int				DEFAULT_CONFIG_PORT						= 80;
const aws_ip_mode		DEFAULT_ETH_IP_MODE						= aws_ip_mode::dhcp;
const uint8_t			DEFAULT_HAS_BME							= 0;
const uint8_t			DEFAULT_HAS_DOME						= 0;
const uint8_t			DEFAULT_HAS_GPS							= 0;
const uint8_t			DEFAULT_HAS_MLX							= 0;
const uint8_t			DEFAULT_HAS_RAIN_SENSOR					= 0;
const uint8_t			DEFAULT_HAS_SC16IS750					= 1;
const uint8_t			DEFAULT_HAS_TSL							= 0;
const uint8_t			DEFAULT_HAS_WS							= 0;
const uint8_t			DEFAULT_HAS_WV							= 0;
const bool				DEFAULT_LOOKOUT_ENABLED					= false;
const float				DEFAULT_MSAS_CORRECTION					= -0.55;
const aws_iface			DEFAULT_PREF_IFACE						= aws_iface::wifi_ap;

const int				DEFAULT_K1								= 33;
const int				DEFAULT_K2								= 0;
const int				DEFAULT_K3								= 8;
const int				DEFAULT_K4								= 100;
const int				DEFAULT_K5								= 100;
const int				DEFAULT_K6								= 0;
const int				DEFAULT_K7								= 0;
const int				DEFAULT_CC_AWS_OVERCAST					= -20;
const int				DEFAULT_CC_AWS_CLOUDY					= -25;
const int				DEFAULT_CC_AAG_OVERCAST					= -15;
const int				DEFAULT_CC_AAG_CLOUDY					= -20;
const bool				DEFAULT_CC_FORMULA_AWS					= true;

const uint16_t			DEFAULT_RAIN_EVENT_GUARD_TIME			= 60;

const bool				DEFAULT_SAFE_CLOUD_COVERAGE_1_ACTIVE	= false;
const bool				DEFAULT_SAFE_CLOUD_COVERAGE_2_ACTIVE	= false;
const uint16_t			DEFAULT_SAFE_CLOUD_COVERAGE_1_DELAY		= 0;
const uint16_t			DEFAULT_SAFE_CLOUD_COVERAGE_2_DELAY		= 0;
const uint16_t			DEFAULT_SAFE_CLOUD_COVERAGE_1_MAX		= 0;
const uint16_t			DEFAULT_SAFE_CLOUD_COVERAGE_2_MAX		= 0;
const bool				DEFAULT_SAFE_RAIN_INTENSITY_ACTIVE		= false;
const uint16_t			DEFAULT_SAFE_RAIN_INTENSITY_DELAY		= 0;
const uint16_t			DEFAULT_SAFE_RAIN_INTENSITY_MAX			= 0;
const bool				DEFAULT_SAFE_WIND_SPEED_ACTIVE			= false;
const uint16_t			DEFAULT_SAFE_WIND_SPEED_DELAY			= 0;
const uint16_t			DEFAULT_SAFE_WIND_SPEED_MAX				= 0;

const bool				DEFAULT_UNSAFE_CLOUD_COVERAGE_1_ACTIVE	= false;
const bool				DEFAULT_UNSAFE_CLOUD_COVERAGE_2_ACTIVE	= false;
const uint16_t			DEFAULT_UNSAFE_CLOUD_COVERAGE_1_DELAY	= 0;
const uint16_t			DEFAULT_UNSAFE_CLOUD_COVERAGE_2_DELAY	= 0;
const uint16_t			DEFAULT_UNSAFE_CLOUD_COVERAGE_1_MAX		= 0;
const uint16_t			DEFAULT_UNSAFE_CLOUD_COVERAGE_2_MAX		= 0;
const bool				DEFAULT_UNSAFE_CLOUD_COVERAGE_1_MISSING	= false;	// if not checked, the key will not be in the submitted json, ditto for other similar parameters
const bool				DEFAULT_UNSAFE_CLOUD_COVERAGE_2_MISSING	= false;
const bool				DEFAULT_UNSAFE_RAIN_EVENT_ACTIVE		= true;
const bool				DEFAULT_UNSAFE_RAIN_EVENT_MISSING		= true;
const bool				DEFAULT_UNSAFE_RAIN_INTENSITY_ACTIVE	= false;
const uint16_t			DEFAULT_UNSAFE_RAIN_INTENSITY_MAX		= 0;
const bool				DEFAULT_UNSAFE_RAIN_INTENSITY_MISSING	= false;
const bool				DEFAULT_UNSAFE_WIND_SPEED_1_ACTIVE		= false;
const bool				DEFAULT_UNSAFE_WIND_SPEED_2_ACTIVE		= false;
const uint16_t			DEFAULT_UNSAFE_WIND_SPEED_1_DELAY		= 0;
const uint16_t			DEFAULT_UNSAFE_WIND_SPEED_2_DELAY		= 0;
const uint16_t			DEFAULT_UNSAFE_WIND_SPEED_1_MAX			= 0;
const uint16_t			DEFAULT_UNSAFE_WIND_SPEED_2_MAX			= 0;
const bool				DEFAULT_UNSAFE_WIND_SPEED_1_MISSING		= false;
const bool				DEFAULT_UNSAFE_WIND_SPEED_2_MISSING		= false;

const aws_wifi_mode		DEFAULT_WIFI_MODE						= aws_wifi_mode::both;
const aws_ip_mode		DEFAULT_WIFI_STA_IP_MODE				= aws_ip_mode::dhcp;

const bool				DEFAULT_DATA_PUSH						= true;
const uint16_t			DEFAULT_PUSH_FREQ						= 300;

const bool				DEFAULT_DISCORD_ENABLED					= false;
const char				DEFAULT_DISCORD_WEBHOOK[]				= "";

const char				DEFAULT_OTA_URL[]						= "https://www.datamancers.net/images/AWS.json";
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

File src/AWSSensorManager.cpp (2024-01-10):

/*	
  	AWSSensorManager.cpp
  	
	(c) 2023 F.Lesage

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
	You should have received a copy of the GNU General Public License along
	with this program. If not, see <https://www.gnu.org/licenses/>.
*/

#include <esp_task_wdt.h>
#include <ESP32Time.h>
// Keep these two to get rid of compile time errors because of incompatibilities between libraries
#include <AsyncUDP_ESP32_W5500.hpp>
#include <ESPAsyncWebSrv.h>

#include "defaults.h"
#include "gpio_config.h"
#include "Hydreon.h"
#include "SC16IS750.h"
#include "AWSGPS.h"
#include "AstroWeatherStation.h"
#include "AWSConfig.h"
#include "SQM.h"
#include "AWSWind.h"
#include "AWSSensorManager.h"
#include "AWS.h"

RTC_DATA_ATTR uint16_t low_battery_event_count = 0;
//RTC_DATA_ATTR byte	prev_available_sensors = 0;
//RTC_DATA_ATTR byte	available_sensors = 0;

SemaphoreHandle_t sensors_read_mutex = NULL;
extern AstroWeatherStation station;

AWSSensorManager::AWSSensorManager( bool _solar_panel, bool _debug_mode )
{
	debug_mode = _debug_mode;

	bme = new Adafruit_BME280();
	mlx = new Adafruit_MLX90614;
	tsl = new Adafruit_TSL2591( 2591 );
	sqm = new SQM( tsl, &sensor_data );
	
	wind_sensors = NULL;
	available_sensors = 0;
	sensor_data = {0};
	solar_panel = _solar_panel;
	polling_ms_interval = DEFAULT_SENSOR_POLLING_MS_INTERVAL;
	
	i2c_mutex = xSemaphoreCreateMutex();

	if ( solar_panel ) {

		pinMode( GPIO_BAT_ADC_EN, OUTPUT );
		pinMode( GPIO_BAT_ADC, INPUT );

	}
}

uint8_t AWSSensorManager::get_available_sensors( void )
{
	return available_sensors;
}

bool AWSSensorManager::get_debug_mode( void )
{
	return debug_mode;
}

SemaphoreHandle_t AWSSensorManager::get_i2c_mutex( void )
{
	return i2c_mutex;
}

sensor_data_t *AWSSensorManager::get_sensor_data( void )
{
	return &sensor_data;
}

bool AWSSensorManager::initialise( I2C_SC16IS750 *sc16is750, AWSConfig *_config, bool _rain_event )
{
	config = _config;

	// FIXME: needed?
	ESP32Time rtc( 0 );

	rain_event = _rain_event;
	initialise_sensors( sc16is750 );

	if ( !solar_panel ) {

		sensors_read_mutex = xSemaphoreCreateMutex();
		std::function<void(void *)> _poll_sensors_task = std::bind( &AWSSensorManager::poll_sensors_task, this, std::placeholders::_1 );
		xTaskCreatePinnedToCore( 
			[](void *param) {
        	    std::function<void(void*)>* poll_proxy = static_cast<std::function<void(void*)>*>( param );
        	    (*poll_proxy)( NULL );
			}, "SensorsTask", 3000, &_poll_sensors_task, 5, &sensors_task_handle, 1 );
	}
	
	return true;
}

void AWSSensorManager::initialise_BME( void )
{
	if ( !bme->begin( 0x76 ) )

		Serial.println( "[ERROR] Could not find BME280." );

	else {

		if ( debug_mode )
			Serial.println( "[INFO] Found BME280." );

		available_sensors |= BME_SENSOR;
	}
}

void AWSSensorManager::initialise_GPS( I2C_SC16IS750 *sc16is750 )
{
	if ( debug_mode )
		Serial.printf( "[DEBUG] Initialising GPS.\n" );

	gps = new AWSGPS( debug_mode );

	if ( ( config->get_has_sc16is750() && !gps->initialise( &sensor_data.gps, sc16is750, i2c_mutex )) || !gps->initialise( &sensor_data.gps )) {

			Serial.printf( "[ERROR] GPS initialisation failed.\n" );
			return;
	}
	gps->start();
	gps->pilot_rtc( true );
	available_sensors |= GPS_SENSOR;
	delay( 1000 );						// Wait a little to get a fix

}

void AWSSensorManager::initialise_MLX( void )
{
	if ( !mlx->begin() )

		Serial.println( "[ERROR] Could not find MLX90614" );

	else {

		if ( debug_mode )
			Serial.println( "[INFO] Found MLX90614" );

		available_sensors |= MLX_SENSOR;
	}
}

void AWSSensorManager::initialise_sensors( I2C_SC16IS750 *_sc16is750 )
{
	if ( solar_panel ) {

		pinMode( GPIO_ENABLE_3_3V, OUTPUT );
		pinMode( GPIO_ENABLE_12V, OUTPUT );
		digitalWrite( GPIO_ENABLE_3_3V, HIGH );
		digitalWrite( GPIO_ENABLE_12V, HIGH );

		delay( 500 );		// MLX96014 seems to take some time to properly initialise
	}
		
	if ( !rain_event && config->get_has_bme() )
		initialise_BME();
		
	if ( !rain_event && config->get_has_mlx() )
		initialise_MLX();
		
	if ( !rain_event && config->get_has_tsl() ) {
		
		initialise_TSL();
		sqm->set_msas_calibration_offset( config->get_msas_calibration_offset() );
		sqm->set_debug_mode( debug_mode );
	}
	
	if ( !rain_event &&  config->get_has_ws() ) {

		wind_sensors = new AWSWindSensor( polling_ms_interval, debug_mode );
		if ( !wind_sensors->initialise_anemometer( config->get_anemometer_model() )) {

			if ( config->get_anemometer_model() == 0x02 ) 
				available_sensors &= ~WIND_VANE_SENSOR;
			available_sensors &= ~ANEMOMETER_SENSOR;

		} else {

			if ( config->get_anemometer_model() == 0x02 ) {

				Serial.printf( "[INFO] Found 2-in-1 wind vane and anemometer.\n" );
				available_sensors |= WIND_VANE_SENSOR;

			} else

				Serial.printf( "[INFO] Found anemometer.\n" );

			available_sensors |= ANEMOMETER_SENSOR;
		}
	}
		
	// Model 0x02 (VMS-3003-CFSFX-N01) is a 2-in-1 device
	if ( !rain_event && config->get_has_wv() && ( config->get_wind_vane_model() != 0x02 ))	{

		if ( !wind_sensors )
			wind_sensors = new AWSWindSensor( polling_ms_interval, debug_mode );

		if ( !wind_sensors->initialise_wind_vane( config->get_wind_vane_model() ))

			available_sensors &= ~WIND_VANE_SENSOR;

		else {

			Serial.printf( "[INFO] Found wind vane.\n" );
			available_sensors |= WIND_VANE_SENSOR;
		}
	}
	if ( config->get_has_rain_sensor() && initialise_rain_sensor())
		available_sensors |= RAIN_SENSOR;

	if ( !rain_event && config->get_has_gps() )
		initialise_GPS( _sc16is750 );
}

bool AWSSensorManager::initialise_rain_sensor( void )
{
	rain_sensor = new Hydreon( RAIN_SENSOR_UART, GPIO_RAIN_SENSOR_TX, GPIO_RAIN_SENSOR_RX, GPIO_RAIN_SENSOR_MCLR, debug_mode );
	return rain_sensor->initialise();
}

void AWSSensorManager::initialise_TSL( void )
{
	if ( !tsl->begin() ) {

		if ( debug_mode )
			Serial.println( "[ERROR] Could not find TSL2591" );

	} else {

		if ( debug_mode )
			Serial.println( "[INFO] Found TSL2591" );

		tsl->setGain( TSL2591_GAIN_LOW );
		tsl->setTiming( TSL2591_INTEGRATIONTIME_100MS );
		available_sensors |= TSL_SENSOR;
	}
}

bool AWSSensorManager::poll_sensors( void )
{
	if ( xSemaphoreTake( sensors_read_mutex, 2000 / portTICK_PERIOD_MS ) == pdTRUE ) {

		retrieve_sensor_data();
		xSemaphoreGive( sensors_read_mutex );
		if ( wind_sensors )
			sensor_data.wind_gust = wind_sensors->get_wind_gust();
		else
			sensor_data.wind_gust = 0.F;
		return true;
	}
	return false;
}

void AWSSensorManager::poll_sensors_task( void *dummy )
{
	while( true ) {

		if ( xSemaphoreTake( sensors_read_mutex, 5000 / portTICK_PERIOD_MS ) == pdTRUE ) {

			retrieve_sensor_data();
			xSemaphoreGive( sensors_read_mutex );
			if ( config->get_has_ws() )
				sensor_data.wind_gust = wind_sensors->get_wind_gust();
			else
				sensor_data.wind_gust = 0.F;
			
		}
		delay( polling_ms_interval );
	}
}

const char *AWSSensorManager::rain_intensity_str( void )
{
	return rain_sensor->rain_intensity_str();	
}
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

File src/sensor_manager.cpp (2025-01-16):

/*
  	AWSSensorManager.cpp

	(c) 2023-2024 F.Lesage

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
	You should have received a copy of the GNU General Public License along
	with this program. If not, see <https://www.gnu.org/licenses/>.
*/

#include <esp_task_wdt.h>
#include <ESP32Time.h>
// Keep these two to get rid of compile time errors because of incompatibilities between libraries
#include <AsyncUDP_ESP32_W5500.hpp>
#include <ESPAsyncWebServer.h>

#include "defaults.h"
#include "gpio_config.h"
#include "SC16IS750.h"
#include "AWSGPS.h"
#include "common.h"
#include "config_manager.h"
#include "SQM.h"
#include "device.h"
#include "Hydreon.h"
#include "anemometer.h"
#include "wind_vane.h"
#include "sensor_manager.h"
#include "AstroWeatherStation.h"

RTC_DATA_ATTR long	prev_available_sensors = 0;	// NOSONAR
RTC_DATA_ATTR long	available_sensors = 0;		// NOSONAR

SemaphoreHandle_t sensors_read_mutex = NULL;	// Issue #7
const aws_device_t ALL_SENSORS	= ( aws_device_t::MLX_SENSOR | aws_device_t::TSL_SENSOR | aws_device_t::BME_SENSOR | aws_device_t::WIND_VANE_SENSOR | aws_device_t::ANEMOMETER_SENSOR | aws_device_t::RAIN_SENSOR | aws_device_t::GPS_SENSOR );
const std::array<etl::string_view,3> CLOUD_COVERAGE_STR = { etl::string_view( "Clear" ), etl::string_view( "Cloudy" ), etl::string_view( "Overcast" ) };

extern AstroWeatherStation station;

aws_device_t operator&( aws_device_t a, aws_device_t b )
{
	return static_cast<aws_device_t>( static_cast<unsigned long>(a) & static_cast<unsigned long>(b) );
}

bool operator!=( unsigned long a, aws_device_t b )
{
	return a != static_cast<unsigned long>(b);
}

aws_device_t operator&( unsigned long a, aws_device_t b )
{
	return static_cast<aws_device_t>( a & static_cast<unsigned long>(b) );
}

aws_device_t operator~( aws_device_t b )
{
	return static_cast<aws_device_t>( ~static_cast<unsigned long>(b) );
}

aws_device_t operator|( aws_device_t a, aws_device_t b )
{
	return static_cast<aws_device_t>( static_cast<unsigned long>(a) | static_cast<unsigned long>(b) );
}

aws_device_t operator*( aws_device_t a, int b )
{
	return static_cast<aws_device_t>( static_cast<unsigned long>(a) * b );
}

aws_device_t& operator|=( aws_device_t& a, aws_device_t b )
{
	return a = static_cast<aws_device_t>( static_cast<unsigned long>(a) | static_cast<unsigned long>(b) );
}

aws_device_t& operator&=( aws_device_t& a, aws_device_t b )
{
	return a = static_cast<aws_device_t>( static_cast<unsigned long>(a) & static_cast<unsigned long>(b) );
}

AWSSensorManager::AWSSensorManager( void ) :
	bme( new Adafruit_BME280() ),
	mlx( new Adafruit_MLX90614() ),
	tsl( new Adafruit_TSL2591( 2591 )),
	i2c_mutex( xSemaphoreCreateMutex() )
{
	memset( &sensor_data, 0, sizeof( sensor_data_t ));
}

aws_device_t AWSSensorManager::get_available_sensors( void )
{
	return available_sensors;
}

bool AWSSensorManager::get_debug_mode( void )
{
	return debug_mode;
}

SemaphoreHandle_t AWSSensorManager::get_i2c_mutex( void )
{
	return i2c_mutex;
}

sensor_data_t *AWSSensorManager::get_sensor_data( void )
{
	return &sensor_data;
}

bool AWSSensorManager::initialise( I2C_SC16IS750 *sc16is750, AWSConfig *_config, bool _rain_event )
{
	config = _config;
	rain_event = _rain_event;
	initialise_sensors( sc16is750 );

	if ( !solar_panel ) {

		sensors_read_mutex = xSemaphoreCreateMutex();
		std::function<void(void *)> _poll_sensors_task = std::bind( &AWSSensorManager::poll_sensors_task, this, std::placeholders::_1 );
		if ( xTaskCreatePinnedToCore(
			[](void *param) {	// NOSONAR
        	    std::function<void(void*)>* poll_proxy = static_cast<std::function<void(void*)>*>( param );
        	    (*poll_proxy)( NULL );
			}, "PollSensorsTask", 10000, &_poll_sensors_task, 5, &sensors_task_handle, 1 ) != pdPASS )
			Serial.printf( "[SENSORMNGR] [ERROR] Could not start task [SensorManagerTask]\n" );
	}

	k[0] = config->get_parameter<int>( "k1" );
	k[1] = config->get_parameter<int>( "k2" );
	k[2] = config->get_parameter<int>( "k3" );
	k[3] = config->get_parameter<int>( "k4" );
	k[4] = config->get_parameter<int>( "k5" );
	k[5] = config->get_parameter<int>( "k6" );
	k[6] = config->get_parameter<int>( "k7" );

	initialised = true;
	return true;
}

void AWSSensorManager::initialise_BME( void )
{
	if ( !bme->begin( 0x76 ) )

		Serial.printf( "[SENSORMNGR] [ERROR] Could not find BME280.\n" );

	else {

		if ( debug_mode )
			Serial.printf( "[SENSORMNGR] [INFO ] Found BME280.\n" );

		available_sensors |= aws_device_t::BME_SENSOR;
	}
}

void AWSSensorManager::initialise_MLX( void )
{
	if ( !mlx->begin() )

		Serial.printf( "[SENSORMNGR] [ERROR] Could not find MLX90614.\n" );

	else {

		if ( debug_mode )
			Serial.printf( "[SENSORMNGR] [INFO ] Found MLX90614.\n" );

		available_sensors |= aws_device_t::MLX_SENSOR;
	}
}

void AWSSensorManager::initialise_sensors( I2C_SC16IS750 *_sc16is750 )
{
	if ( solar_panel ) {

		pinMode( GPIO_ENABLE_3_3V, OUTPUT );
		pinMode( GPIO_ENABLE_12V, OUTPUT );
		digitalWrite( GPIO_ENABLE_3_3V, HIGH );
		digitalWrite( GPIO_ENABLE_12V, HIGH );

		delay( 500 );		// MLX96014 seems to take some time to properly initialise
	}

	if ( !rain_event && config->get_has_device( aws_device_t::BME_SENSOR ) )
		initialise_BME();

	if ( !rain_event && config->get_has_device( aws_device_t::MLX_SENSOR ) )
		initialise_MLX();

	if ( !rain_event && config->get_has_device( aws_device_t::TSL_SENSOR ) ) {

		initialise_TSL();
		sqm.initialise( tsl, &sensor_data.sqm, config->get_parameter<float>( "msas_calibration_offset" ), debug_mode );
	}

	if ( !rain_event &&  config->get_has_device( aws_device_t::ANEMOMETER_SENSOR ) ) {

		if ( !anemometer.initialise( &rs485_bus, polling_ms_interval, config->get_parameter<int>( "anemometer_model" ), debug_mode ))

			available_sensors &= ~aws_device_t::ANEMOMETER_SENSOR;

		else {

			Serial.printf( "[SENSORMNGR] [INFO ] Found anemometer.\n" );
			available_sensors |= aws_device_t::ANEMOMETER_SENSOR;
		}
	}

	if ( !rain_event && config->get_has_device( aws_device_t::WIND_VANE_SENSOR ) ) {

		if ( !wind_vane.initialise( &rs485_bus, config->get_parameter<int>( "wind_vane_model" ), debug_mode ))

			available_sensors &= ~aws_device_t::WIND_VANE_SENSOR;

		else {

			Serial.printf( "[SENSORMNGR] [INFO ] Found wind vane.\n" );
			available_sensors |= aws_device_t::WIND_VANE_SENSOR;
		}
	}

	if ( config->get_has_device( aws_device_t::RAIN_SENSOR ) && initialise_rain_sensor())
		available_sensors |= aws_device_t::RAIN_SENSOR;

}

bool AWSSensorManager::initialise_rain_sensor( void )
{
	return rain_sensor.initialise( Serial1, debug_mode );
}

void AWSSensorManager::initialise_TSL( void )
{
	if ( !tsl->begin() ) {

		if ( debug_mode )
			Serial.printf( "[SENSORMNGR] [ERROR] Could not find TSL2591.\n" );

	} else {

		if ( debug_mode )
			Serial.printf( "[SENSORMNGR] [INFO ] Found TSL2591.\n" );

		tsl->setGain( TSL2591_GAIN_LOW );
		tsl->setTiming( TSL2591_INTEGRATIONTIME_100MS );
		available_sensors |= aws_device_t::TSL_SENSOR;
	}
}
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

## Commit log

2023-03-05 Add schematics
2023-03-08 Move RG9 power to 12V after brownouts
    Side effect is the move of the relay between the MT3608 out and the wind sensor power connector
2023-03-08 Rename schematics
2023-03-08 Change 5V relay to 12V
2023-03-08 v1.0 schematics
2023-03-08 RG9 initialisation fix and some more debug output
    [AstroWeatherStation.ino]
2023-03-15 Battery level estimation improvement. RG9 initialisation improvements. Cosmetic changes
2023-03-15 Schematics update
2023-03-20 Fixed universal PCB size and a couple of tracks
2023-03-21 Added BOM
2023-03-21 Fixed voltage divider resistor value
2023-03-23 Added 4 screws
2023-03-24 Revert "Fixed universal PCB size and a couple of tracks"
    This reverts commit 25c9fbc3a4d8009c1c3433190107a68da0614b9b.
2023-03-25 RG9 support improvements. Battery level improvements
2023-03-25 Align R1 value with BOM
2023-03-28 Battery level estimation improvement
2023-04-03 Added female pins for buck converters
2023-04-03 Rework of the schematics
2023-04-10 Added battery life span
2023-05-01 Remove SQUBE flow
2023-05-01 Remove CodeQL flow
2023-11-07 Merge 3.0 into main branch (#25)
    * SQM feature.
    * Reference for lux to W/m2
    * Using referenced formulas for SQM
    * Update BOM
    * Update README.md
    * Capability to disable sensors in runtime config
    * Major rework, OO design.
    * Added support for ultrasonic wind sensor VMS-3003-CFSFX-N01
    * Thread for sensor readings
    * 12V version: gerber and schematics
    * Close #4 #5 #8 #11 #12 #16
    [AWS_12V_3.0.0_contour.gm1, AWS_12V_3.0.0_copperBottom.gbl, AWS_12V_3.0.0_copperTop.gtl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]
2023-11-20 One step closer to 3.0.0 FF (#32)
    * SQM feature. Code cleaning. Remove explicit use of String class which causes random bugs
    * Update for the 1.2 branch
    * Got the old breadboard design
    * Got the old BOM
    * MSAS cannot be negative
    * Code cleaning
    * Initial commit of 1.3
    * Removed required commented code and a couple of bugs
    * Small fixes
    * Created 2.0 after changes in relays and their commands. Bigger perfboard.
    * Fixed glitches
    * Big refactoring: do not power sensors in case of rain event / Use of HW config
    * Update README.md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
    [AWS_12V_3.0.0_copperBottom.gbl, AWS_12V_3.0.0_copperTop.gtl, AWS_12V_3.0.0_maskBottom.gbs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]
2023-11-20 Close #31, Close #30, Close 29, Close #28, Close #20, Close #18, Close #13, Close #12, Close #11, Close #10, Close #9 (#33)
    * Added one dome status input pin, small part moves and added ground fill
    * Close #1 #8 #9 #10 #11 #12 #16 #18 #19 #27 #29
    * Small fixes after merge with main
    [AWS_12V_3.0.0_copperBottom.gbl, AWS_12V_3.0.0_copperTop.gtl, AWS_12V_3.0.0_maskBottom.gbs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]
2023-12-25 Bug fixes (#57)
    * Fixed bug in run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
    [AWSGPS.cpp, AWSSensorManager.cpp, AWSSensorManager.h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]
2023-12-26 Bug fixes (#59)
    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
    [AstroWeatherStation.ino]
2023-12-26 Close issues and update/extend schematics (#60)
    * Update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
    [8x12_AWS_3.0.0_PANEL_contour.gm1, 8x12_AWS_3.0.0_PANEL_copperBottom.gbl, 8x12_AWS_3.0.0_PANEL_copperTop.gtl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]
2023-12-30 Bug fixes (#70)
    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
    [8x12_AWS_3.0.0_PANEL_copperBottom.gbl, 8x12_AWS_3.0.0_PANEL_copperTop.gtl, 8x12_AWS_3.0.0_PANEL_maskBottom.gbs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]
2024-01-01 Bug fix / Data backlog implementation (#72)
    * Close #63, Close #71
    [AWSSensorManager.cpp, AstroWeatherStation.h, AstroWeatherStation.ino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]
2024-01-03 Bug fixes (#80)
    * Close #78, Close #64, Close #69, Close #79
    [AWSSensorManager.cpp, AstroWeatherStation.h, AstroWeatherStation.ino]
2024-01-06 Bug fixes (#86)
    * Close #8, Close #82, Close #85
    [AWSGPS.cpp, AWSSensorManager.cpp, AWSSensorManager.h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]
2024-01-10 Bug fixes (#91)
    * Close #81, Close #89, Close #88, Close #84, Close #87
    [AWSGPS.cpp, AWSSensorManager.cpp, AstroWeatherStation.h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]
2024-01-10 Revert "Close #90"
    This reverts commit 5c2133ff8bea0befb7591390c653a5155212a641.
    [dome.cpp]
2024-02-05 Fixing code smells (#113)
    * Fixing code smells with sometimes big changes
    [AWSGPS.cpp, AstroWeatherStation.cpp, AstroWeatherStation.h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]
2024-02-05 Fixing code smells (#114)
    * Fixing code smells
    [AWSGPS.cpp, AstroWeatherStation.cpp, AstroWeatherStation.h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]
2024-02-05 Fixing code smells (#115)
    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
    [AWSGPS.cpp, AstroWeatherStation.cpp, SQM.cpp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]
2024-02-05 Fixing code smells (#116)
    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
    [AstroWeatherStation.cpp, AstroWeatherStation.h, config_manager.cpp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]
2024-02-07 Fixing code smells (#117)
    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
    [AstroWeatherStation.cpp, AstroWeatherStation.h, AstroWeatherStation.ino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]
2024-02-07 Fixing code smells (#118)
    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
    [AstroWeatherStation.cpp, AstroWeatherStation.h, SC16IS750.cpp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]
2024-02-08 Fixing code smells (#119)
    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
    [AWSGPS.cpp, AstroWeatherStation.cpp, AstroWeatherStation.h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]
2024-02-08 Fixing code smells (#121)
    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
    [AstroWeatherStation.cpp, SC16IS750.cpp, config_server.cpp]
2024-02-09 Fixing code smells (#123)
    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
    [AWSGPS.cpp, AstroWeatherStation.cpp, AstroWeatherStation.h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]
2024-02-09 Fixing code smells (#126)
    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
    [AstroWeatherStation.cpp, AstroWeatherStation.h, AstroWeatherStation.ino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]
2024-02-10 Fixing code smells (#127)
    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
    [AstroWeatherStation.cpp, AstroWeatherStation.h, config_manager.cpp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]
2024-02-18 Fixing code smells (#131)
    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
    [AWSLookout.cpp, AstroWeatherStation.cpp, AstroWeatherStation.h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]
2024-02-20 Fixing code smells (#136)
    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
    [AWSLookout.cpp, AstroWeatherStation.cpp, AstroWeatherStation.ino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]
2024-02-21 Bug fixes and code smells (#137)
    * Fixing minor bugs and code smells
    [AWSLookout.cpp, AstroWeatherStation.cpp, AstroWeatherStation.h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]
2024-02-26 Bug fixes (#139)
    * Close #133, close #83, code smells
    [AWSLookout.cpp, AstroWeatherStation.cpp, AstroWeatherStation.h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]
2024-02-26 Fixing code smells (#140)
    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
    [AWSLookout.cpp, AstroWeatherStation.cpp, config_manager.cpp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]
2024-02-27 Fixing code smells (#141)
    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
    [AWSLookout.cpp, AstroWeatherStation.cpp, AstroWeatherStation.h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]
2024-02-27 Fixing code smells (#146)
    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
    [AWSLookout.cpp, AstroWeatherStation.cpp, config_server.cpp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]
2024-03-06 Minor improvements, bug fixes and code smells (#159)
    * Close #142, close #145, Close #43, Close #134, fixing code smells
    [AWSGPS.cpp, AWSLookout.cpp, AstroWeatherStation.cpp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]
2024-05-22 3.0.1 Bug fix, 1st commit (#168)
    * Close #155, Close #157, Close #166, Close #167
    [AWSLookout.cpp, AWSNetwork.cpp, AstroWeatherStation.cpp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]
2024-12-03 Changed ESPAsyncWebSrv for ESPAsyncWebServer librabry. Added factory reset function. Other minor changes
    [AWSLookout.cpp, AWSNetwork.cpp, AWSUpdater.cpp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]
2025-01-07 Bug fix and small improvements (#183)
    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
    [AWSLookout.cpp, AWSNetwork.cpp, AstroWeatherStation.cpp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]
2025-01-07 Close #184 (#185)
    * Fixed bug in r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
    [AWSNetwork.cpp, AstroWeatherStation.h, config_manager.cpp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]
2025-01-07 Fix code smells (#186)
    * Fixed bug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
    [AstroWeatherStation.cpp, Hydreon.cpp, SC16IS750.cpp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]
2025-01-08 Fix code smells (#187)
    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
    [AWSLookout.cpp, AWSUpdater.cpp]
2025-01-10 Fix code smells (#188)
    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
    [AWSUpdater.cpp, AstroWeatherStation.h, config_manager.h]
2025-01-11 Fix code smells (#189)
    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
    [AWSUpdater.cpp, config_manager.cpp, config_server.cpp]
2025-01-11 Fix code smells (#190)
    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
    [AWSNetwork.cpp, AstroWeatherStation.cpp, config_manager.cpp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]
2025-01-11 Fix code smells (#191)
    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
    [AWSNetwork.cpp, AstroWeatherStation.cpp, AstroWeatherStation.h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]
2025-01-11 Fix code smells (#192)
    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
    [AstroWeatherStation.cpp, AstroWeatherStation.h]
2025-01-12 Fix code smells (#193)
    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
    [AstroWeatherStation.cpp]
2025-01-13 Fix code smells (#194)
    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
    [anemometer.cpp, rs485_device.cpp, wind_vane.cpp]
2025-01-13 Remove duplicated lines (#195)
    * F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
    [alpaca_server.cpp]
2025-01-16 Fix code smells. Close #176. Close #196. Close #149. Close #143 (#197)
    *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
    [AWSGPS.cpp, AWSLookout.cpp, AstroWeatherStation.cpp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]
2025-01-16 Drop code smell (#198)
    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
    [alpaca_server.cpp]
2025-01-16 Fix code smells (#199)
    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
    [alpaca_server.cpp, config_manager.cpp]
2025-01-18 Fix robustness issues. Close #200 (#201)
    * Update README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
    [AWSLookout.cpp, AstroWeatherStation.cpp, AstroWeatherStation.h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]
2025-01-18 Fix reopened #200 (#202)
    * Fixed b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
    [alpaca_server.cpp]
2025-01-21 Close #203 (#204)
    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
    [AWSGPS.cpp, AWSLookout.cpp, AstroWeatherStation.cpp]

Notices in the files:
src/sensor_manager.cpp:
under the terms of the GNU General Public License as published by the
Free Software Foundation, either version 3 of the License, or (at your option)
